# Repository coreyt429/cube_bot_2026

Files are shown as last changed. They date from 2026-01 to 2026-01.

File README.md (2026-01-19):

Cube Solver Bot (2026)

This repo tracks my 2026 rebuild of a Rubik's cube solving robot. In 2025 I built
https://www.rcr3d.com as an ROS2 learning project. The mechanics worked and the
solver logic was in place, but I stalled on computer vision. After a rough fall
shattered that robot, I started over with fresh parts and a new mechanical
layout.

Origins
- Base design: https://www.printables.com/model/17306-rubik-cube-solver-robot-v-shape
- Salvaged parts: Pololu Maestro Mini 12 + servos from the first cube_bot
- Replacement parts: https://www.thingiverse.com/thing:2800244
- New build: spare Raspberry Pi, new 3D printer, lots of filament

I redesigned the baseplate to fit my electronics and replaced a few missing
parts from the original project.

Status
Hardware
- Left gripper: assembled and tested, mounted
- Right gripper: assembled, tested, mounted
- Camera: mounted and tested
- buttons and screen: affixed to PCB and tested
- final assembly: complete

Software
- Pi Zero: 
- Pololu Maestro 12: validated previous configuration and tools
  - https://www.pololu.com/docs/0J40/3.b
- cube_bot.py: updated for new claw configuration; tested with calibrate.py
- arm.py: updated for new claw configuration; tested with calibrate.py
- calibrate.py: updated for new cube_bot.py and arm.py
- cube.py: unchanged
- maestro.py: unchanged
- solver.py: unchanged
- visualize.py: unchanged

Notes and Direction
The original project used a "human-like" solve approach. It was too slow on a
physical cube, so I added Kociemba for faster solutions. The old system kept
the physical cube and logical cube in sync via signal emits, so the on-screen
cube matched the real cube.

For this iteration, I am leaning toward a web-based interface for:
- Live camera view
- Manual arm control and calibration
- Cube motion control

This build also adds buttons and a small LCD for more hands-on control and
learning.

Updates
20260113
  - Testing hardware now.  I can move to final assembly once I have a longer camera cable.
  - Testing motion, a lot of my previous work will translate. I'm finding that the claws
    are a danger to each other with or without the cube. Bot will need to be aware of
    and orchestrate arms to avoid disaster.  I may also need to use the camera to detect
    bad cube alignment.
  - baseplate redesigned again to allow more headroom for wiring.
  - Next steps:
    - final assembly
    - cube loading process
    - basic cube moves U, D, L, R, F, B

20260119
  - Hardware assembled.
  - scrapped uv for pi side python.  Too many issues working with buttons and cam, and the OS python seems sufficient.
  - calibration and rudimentary tests for display, buttons, and cam passed
  - Next Steps:
    - cube loading process:
      - use buttons and display
      - user experience:
        - select load menu
        - grippers open then close slightly to approximate cube size
        - user uses up and down buttons to adjust grip
        - user presses select to continue
    - calibration:
      - menu tree:
        - Left/Right:
          - Gripper:
             - Open
             - Close
          - Rotation:
            - 0
            - 90
            - 180
            - 270
      - user experience:
        - user navigates the menu to select the postion that need adjusting
        - user uses up and down buttons to adjust position
        - user uses select button to save and go back to the menu
    - basic cube moves U, D, L, R, F, B

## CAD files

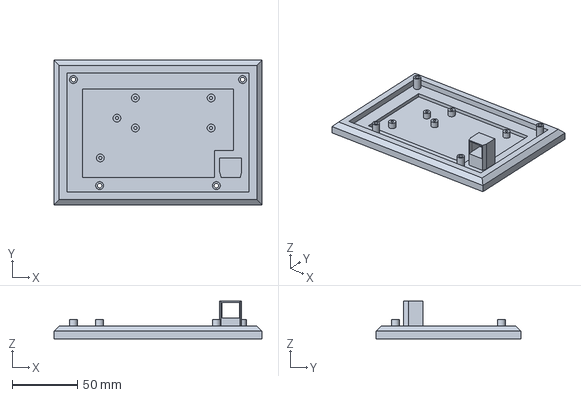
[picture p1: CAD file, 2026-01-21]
printed_parts/new_base_plate.FCStd
159.3 x 110.9 x 29.0 mm

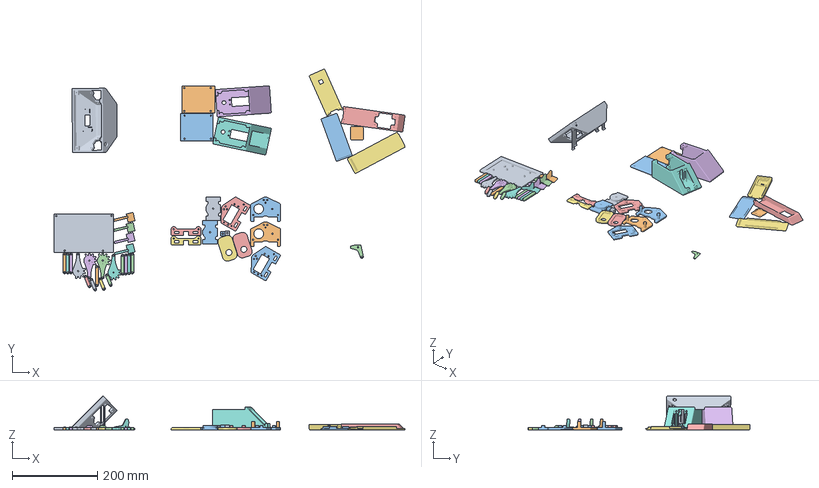
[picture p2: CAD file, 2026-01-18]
printed_parts/rubiks_robot_2026.3mf
821.2 x 519.1 x 78.8 mm
body.stl
gripper_arm_right.stl x 2
gripper_middle_plate_update.stl x 2
cam_lower_part.stl
gripper_arm_left.stl x 2
cam_lower_lid.stl
cam_upper_lid.stl
gear_hornT25_L_V2.stl x 2
gripper_lower_plate_update.stl x 2
cam_upper_part.stl
gear_r_update.stl x 2
cam_internal_cover.stl
rod_X4.stl x 8
servo_cover_2x.stl x 2
rear_plate_update.stl x 2
gripper_upper_plate_update.stl x 2
interlink_right_arm_cam_arm_2x.stl x 2
gripper_short_connect_2x.stl x 4
arm_left_body.stl
arm_right_body.stl
arm_left_lid.stl
arm_right_lid.stl
wb_shield.stl

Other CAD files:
printed_parts/new_base_plate-Body-updated.3mf
printed_parts/new_base_plate.3mf

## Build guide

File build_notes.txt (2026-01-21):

OS:
  - init raspbian OS with pi Imager
  - update os:
    - sudo apt update
    - sudo apt upgrade
    - sudo apt install -y libcap-dev pkg-config build-essential python3-dev python3-luma.oled python3-pil

  - sudo raspi-config:
    - enable VNC
    - enable i2c
  - install os components:
    - sudo apt install git python3-pip python3-setuptools python3-smbus i2c-tools
  - setup python environment:
    - curl -LsSf https://astral.sh/uv/install.sh | sh
    - git clone https://github.com/coreyt429/cube_bot_2026.git
    - cd cube_bot_2026
    - uv sync
    - uv pip install gpiod
    - uv pip install luma.oled pillow
    - 

sudo nano /etc/systemd/system/boot-display-message.service

[Unit]
Description=Show boot progress message on OLED
# If your display is I2C, make sure i2c-dev is loaded first
After=systemd-modules-load.service
# If your script needs the filesystem ready
After=local-fs.target
# If the OLED is part of your normal app stack, you can also do:
# After=multi-user.target

[Service]
Type=oneshot
User=coreyt
WorkingDirectory=/home/coreyt/cube_bot_2026
ExecStart=/usr/bin/python3 /home/coreyt/cube_bot_2026/display_message.py "Booting..."
# If you need I2C access as non-root:
# SupplementaryGroups=i2c,gpio

[Install]
WantedBy=multi-user.target

sudo nano /etc/systemd/system/cubebot-main.service
[Unit]
Description=CubeBot Main Application
# Wait until the system is fully usable
After=multi-user.target
# Make sure the boot message ran first
After=boot-display-message.service

[Service]
Type=simple
User=coreyt
WorkingDirectory=/home/coreyt/cube_bot_2026

# Use system python explicitly (avoid pyenv surprises at boot)
ExecStart=/usr/bin/python3 /home/coreyt/cube_bot_2026/main.py

# Restart if it crashes (useful for robots)
Restart=on-failure
RestartSec=2

# If you need GPIO/I2C as non-root
SupplementaryGroups=gpio

# Ensure stdout/stderr go to journal
StandardOutput=journal
StandardError=journal

[Install]
WantedBy=multi-user.target

sudo systemctl daemon-reload
sudo systemctl enable cubebot-main.service

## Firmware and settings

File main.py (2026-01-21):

"""
Main.py not used yet.
"""

from display import Display
from menu import Menu, Buttons
from cube_bot import CubeBot


def calibrate(display, buttons: Buttons, bot: CubeBot, arm_key: str, servo_key: str, position) -> None:
    """calibrate servo"""
    arm = bot.arms[arm_key]
    servo = arm.servos[servo_key]
    display.draw_message(
        "Calibrate",
        [
            f"Arm: {arm_key}",
            f"Servo: {servo_key}",
            f"Position: {position}",
            "",
            "Up: move -100 qus",
            "Down: move +100 qus",
            "Select: set position",
        ],
    )
    if servo_key == "rotate":
        arm.set_degrees(position)
    elif servo_key == "open":
        if position == "open":
            arm.open()
        elif position == "close":
            arm.close()
    while True:
        if buttons.wait(timeout=0.05):
            for ev in buttons.read_events():
                if ev.edge != "PRESS":
                    continue
                if ev.btn == "up":
                    current_qus = servo.qus
                    servo.set_qus(current_qus - 100, wait=True)
                elif ev.btn == "down":
                    current_qus = servo.qus
                    servo.set_qus(current_qus + 100, wait=True)
                elif ev.btn == "select":
                    calibrated_qus = int(getattr(servo, "qus", 0) or 0)
                    arm.cfg.qus[str(position)] = calibrated_qus
                    arm_cfg = bot.cfg.setdefault("arms", {}).setdefault(
                        arm.cfg.key, {}
                    )
                    arm_cfg.setdefault("qus", {})[str(position)] = calibrated_qus
                    arm_cfg["qus"]["state"] = str(position)
                    bot.save_config()
                    display.draw_message("Calibrate", ["Position set", "Exit"])
                    return
                display.draw_message(
                    "Calibrate",
                    [
                        f"Arm: {arm_key}",
                        f"Servo: {servo_key}",
                        f"Position: {position}",
                        f"Current qus: {servo.qus}",
                        "",
                        "Up: move -100 qus",
                        "Down: move +100 qus",
                        "Select: set position",
                    ],
                )

def load_cube(display, buttons: Buttons, bot: CubeBot) -> None:
    """Load cube into CubeBot"""
    bot.arms["l"].open()
    bot.arms["r"].open()
    display.draw_message("Load Cube", ["", "Up: close  Down: open", "Select: exit"])
    positions = []
    for arm in bot.arms.values():
        servo = arm.servos["open"]
        servo.set_qus(8000, wait=True)
        positions.append(servo.qus)
    while True:
        if buttons.wait(timeout=0.05):
            for ev in buttons.read_events():
                if ev.edge != "PRESS":
                    continue
                if ev.btn == "up":
                    positions.clear()
                    for arm in bot.arms.values():
                        servo = arm.servos["open"]
                        current_qus = servo.qus
                        servo.set_qus(current_qus - 100, wait=True)
                        positions.append(servo.qus)
                elif ev.btn == "down":
                    positions.clear()
                    for arm in bot.arms.values():
                        servo = arm.servos["open"]
                        current_qus = servo.qus
                        servo.set_qus(current_qus + 100, wait=True)
                        positions.append(servo.qus)
                elif ev.btn == "select":
                    for arm in bot.arms.values():
                        servo = arm.servos["open"]
                        closed_qus = int(getattr(servo, "qus", 0) or 0)
                        arm.cfg.qus["closed"] = closed_qus
                        arm_cfg = bot.cfg.setdefault("arms", {}).setdefault(
                            arm.cfg.key, {}
                        )
                        arm_cfg.setdefault("qus", {})["closed"] = closed_qus
                        arm_cfg["qus"]["state"] = "closed"
                    bot.save_config()
                    display.draw_message("Load Cube", ["Exit"])
                    return
                display.draw_message(
                    "Load Cube",
                    [str(positions), "Up: close  Down: open", "Select: exit"],
                )


def unload_cube(display, buttons: Buttons, bot: CubeBot) -> None:
    """Unload cube from CubeBot"""
    bot.arms["l"].open()
    bot.arms["r"].open()
    display.draw_message("Unload Cube", [""])


def main():
    """Main logic"""
    bot = CubeBot("calibration")
    menu_definition = [
        {
            "cube": {
                "load cube": {
                    "action": load_cube,
                    "parameters": [bot],
                },
                "unload cube": {
                    "action": unload_cube,
                    "parameters": [bot],
                },
            },
            "calibrate": {
                "left": {
                    "gripper": {
                        "open": {
                            "action": calibrate,
                            "parameters": [bot, "l", "open", "open"],
                        },
                        "close": {
                            "action": calibrate,
                            "parameters": [bot, "l", "open", "close"],
                        },
                    },
                    "rotate": {
                        "0 deg": {
                            "action": calibrate,
                            "parameters": [bot, "l", "rotate", 0],
                        },
                        "90 deg": {
                            "action": calibrate,
                            "parameters": [bot, "l", "rotate", 90],
                        },
                        "180 deg": {
                            "action": calibrate,
                            "parameters": [bot, "l", "rotate", 180],
                        },
                        "270 deg": {
                            "action": calibrate,
                            "parameters": [bot, "l", "rotate", 270],
                        },
                    },
                },
                "right": {
                    "gripper": {
                        "open": {
                            "action": calibrate,
                            "parameters": [bot, "r", "open", "open"],
                        },
                        "close": {
                            "action": calibrate,
                            "parameters": [bot, "r", "open", "close"],
                        },
                    },
                    "rotate": {
                        "0 deg": {
                            "action": calibrate,
                            "parameters": [bot, "r", "rotate", 0],
                        },
                        "90 deg": {
                            "action": calibrate,
                            "parameters": [bot, "r", "rotate", 90],
                        },
                        "180 deg": {
                            "action": calibrate,
                            "parameters": [bot, "r", "rotate", 180],
                        },
                        "270 deg": {
                            "action": calibrate,
                            "parameters": [bot, "r", "rotate", 270],
                        },
                    },
                },
            },
        }
    ]

    display = Display()
    menu = Menu(display=display, menu_definition=menu_definition, title="CubeBot")
    menu.run()


if __name__ == "__main__":
    main()

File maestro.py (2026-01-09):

"""
Module for controlling the Maestro servo controller
"""

# maestro.py
import time
import logging
from typing import Optional
from dataclasses import dataclass
import serial

logger = logging.getLogger("maestro")


def us_to_qus(us: int) -> int:
    """
    Convert microseconds to quarter-microseconds.
    """
    if logger.isEnabledFor(logging.DEBUG):
        logger.debug("us_to_qus called with us=%d", us)
    return int(us) * 4


# --- Servo config dataclass ---
@dataclass
class ServoConfig:
    """Configuration for a servo motor."""

    limits: Optional[list[int]] = None
    speed: int = 75
    accel: int = 0
    initial_deg: Optional[int] = None
    span_deg: int = 270


class Maestro:
    """
    Talk to a Pololu Maestro over the USB 'Command Port' using the Compact Protocol.
    Targets are in quarter-microseconds (e.g., 1500 µs => 6000).
    """

    def __init__(self, port: str, baud: int = 9600, timeout: float = 0.1):
        logger.debug(
            "Maestro.__init__(port=%s, baud=%s, timeout=%s)", port, baud, timeout
        )
        # For USB Command Port, the baud setting is ignored but must be valid.
        self.port = port
        self.baud = baud
        self.timeout = timeout
        self.ser = serial.Serial(port=port, baudrate=baud, timeout=timeout)

    def __str__(self) -> str:
        return f"Maestro(port={self.port}, baud={self.baud}, timeout={self.timeout})"

    def close(self):
        """
        Close the serial connection.
        """
        logger.debug("Maestro.close called")
        self.ser.close()

    # ---- Core commands (Compact Protocol) ----
    def set_target_qus(self, channel: int, target_qus: int):
        """
        Set servo pulse. Example: 1500µs -> 1500*4 = 6000.
        """
        logger.debug("set_target_qus(channel=%s, target_qus=%s)", channel, target_qus)
        # Set servo pulse. Example: 1500µs -> 1500*4 = 6000
        if not 0 <= channel <= 23:
            raise ValueError("channel must be 0–23")
        if not 0 <= target_qus <= 16383:
            raise ValueError("target_qus must be 0–16383 (14-bit)")
        cmd = bytes([0x84, channel, target_qus & 0x7F, (target_qus >> 7) & 0x7F])
        self.ser.write(cmd)

    def set_speed(self, channel: int, value: int):
        """Limit speed (0 = unlimited). Units: (quarter-µs)/(10 ms)."""
        logger.debug("set_speed(channel=%s, value=%s)", channel, value)
        cmd = bytes([0x87, channel, value & 0x7F, (value >> 7) & 0x7F])
        self.ser.write(cmd)

    def set_accel(self, channel: int, value: int):
        """Limit acceleration (0 = unlimited). Units: (quarter-µs)/(10 ms)^2."""
        logger.debug("set_accel(channel=%s, value=%s)", channel, value)
        cmd = bytes([0x89, channel, value & 0x7F, (value >> 7) & 0x7F])
        self.ser.write(cmd)

    def get_position(self, channel: int) -> Optional[int]:
        """Returns target in quarter-µs, or None on timeout."""
        logger.debug("get_position(channel=%s)", channel)
        self.ser.write(bytes([0x90, channel]))
        resp = self.ser.read(2)
        if len(resp) != 2:
            return None
        return resp[0] + 256 * resp[1]

    def is_moving(self) -> bool:
        """True if any servo is still moving toward its target."""
        logger.debug("is_moving()")
        self.ser.write(bytes([0x93]))
        resp = self.ser.read(1)
        return bool(resp and resp[0])

    def go_home(self):
        """Send the 'go home' command to the Maestro."""
        logger.debug("go_home()")
        self.ser.write(bytes([0xA2]))

    # Per-channel soft limits (μs). Change per your servo if needed.
    _limits = {}  # ch -> (min_us, max_us, neutral_us)

    def set_limits(
        self,
        channel: int,
        min_us: int = 1100,
        max_us: int = 1900,
        neutral_us: int = 1500,
    ):
        """
        Set per-channel soft limits.
        """
        logger.debug(
            "set_limits(channel=%s, min_us=%s, max_us=%s, neutral_us=%s)",
            channel,
            min_us,
            max_us,
            neutral_us,
        )
        if min_us >= max_us:
            raise ValueError("min_us must be < max_us")
        self._limits[channel] = (min_us, max_us, neutral_us)

    def _clamp_us(self, channel: int, us: int) -> int:
        """
        Clamp a microsecond value to the limits set for a channel.
        """
        logger.debug("_clamp_us(channel=%s, us=%s)", channel, us)
        lo, hi, _ = self._limits.get(channel, (1100, 1900, 1500))
        return max(lo, min(hi, int(us)))

    # Already had set_target_qus; add μs & degrees conveniences:
    def set_us(self, channel: int, us: int):
        """
        Set the target position for a servo channel in microseconds.
        """
        logger.debug("set_us(channel=%s, us=%s)", channel, us)
        us = self._clamp_us(channel, us)
        self.set_target_qus(channel, us_to_qus(us))

    def wait(self):
        """Wait until all servos are no longer moving."""
        logger.debug("wait()")
        while self.is_moving():
            time.sleep(0.15)

    def set_degrees(self, channel: int, deg: float, span_deg: float = 180.0):
        """
        Map degrees to μs within this channel's [min,max].
        span_deg is the mechanical travel you're targeting (commonly ~180).
        """
        logger.debug(
            "set_degrees(channel=%s, deg=%s, span_deg=%s)", channel, deg, span_deg
        )
        lo, hi, _ = self._limits.get(channel, (1100, 1900, 1500))
        # Map 0..span_deg to lo..hi (linear)
        deg = max(0.0, min(span_deg, float(deg)))
        us = lo + (hi - lo) * (deg / span_deg)
        self.set_us(channel, int(us))

    def center(self, channel: int):
        """
        Center the servo on the specified channel.
        """
        logger.debug("center(channel=%s)", channel)
        _, _, neu = self._limits.get(channel, (1100, 1900, 1500))
        self.set_us(channel, neu)

    def tame(self, channel: int, speed: int = 10, accel: int = 5):
        """
        Set the speed and acceleration for a servo channel.
        """
        logger.debug("tame(channel=%s, speed=%s, accel=%s)", channel, speed, accel)
        self.set_speed(channel, speed)
        self.set_accel(channel, accel)


# def gentle_calibrate(
#     m: Maestro, channel: int = 0, start=(500, 2500), step=20, pause=0.15
# ):
#     logger.debug(
#         f"gentle_calibrate called with channel={channel},
# start={start}, step={step}, pause={pause}"
#     )
#     lo, hi = start
#     m.set_limits(channel, lo, hi)
#     m.tame(channel, speed=10, accel=5)
#     m.center(channel)
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

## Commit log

2026-01-09 intial refactor to new two arm/clamp format
2026-01-12 camera test
2026-01-13 fix arm reset
2026-01-18 button debug
    [new_base_plate.3mf, new_base_plate.FCStd, rubiks_robot_2026.3mf]
2026-01-18 fix buttons?
2026-01-19 update readme after assembly
2026-01-19 attempt to quieten servos
2026-01-21 display module
    [new_base_plate-Body-updated.3mf, new_base_plate.FCStd]
2026-01-21 button events
2026-07-21 remap buttons
2026-07-21 add checks to minimize arm movements
